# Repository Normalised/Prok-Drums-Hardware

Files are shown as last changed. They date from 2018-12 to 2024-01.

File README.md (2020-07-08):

# Prok-Drums-Hardware

Prok Drums are open hardware, they are a modified version of the Music Thing Modular Radio Music module by Tom Whitwell and have the Creative Commons license CC-BY-SA: Attribution / ShareAlike. 

If you use any work from this hardware, you should credit Tom Whitwell, and you must republish any changes you make under the same license. 

Please remove all references to Prok and Thonk from the PCB silkscreen and project name before republishing.

The names Prok and Thonk, their associated logos and module names are not open source and should not be used in any derivative works.

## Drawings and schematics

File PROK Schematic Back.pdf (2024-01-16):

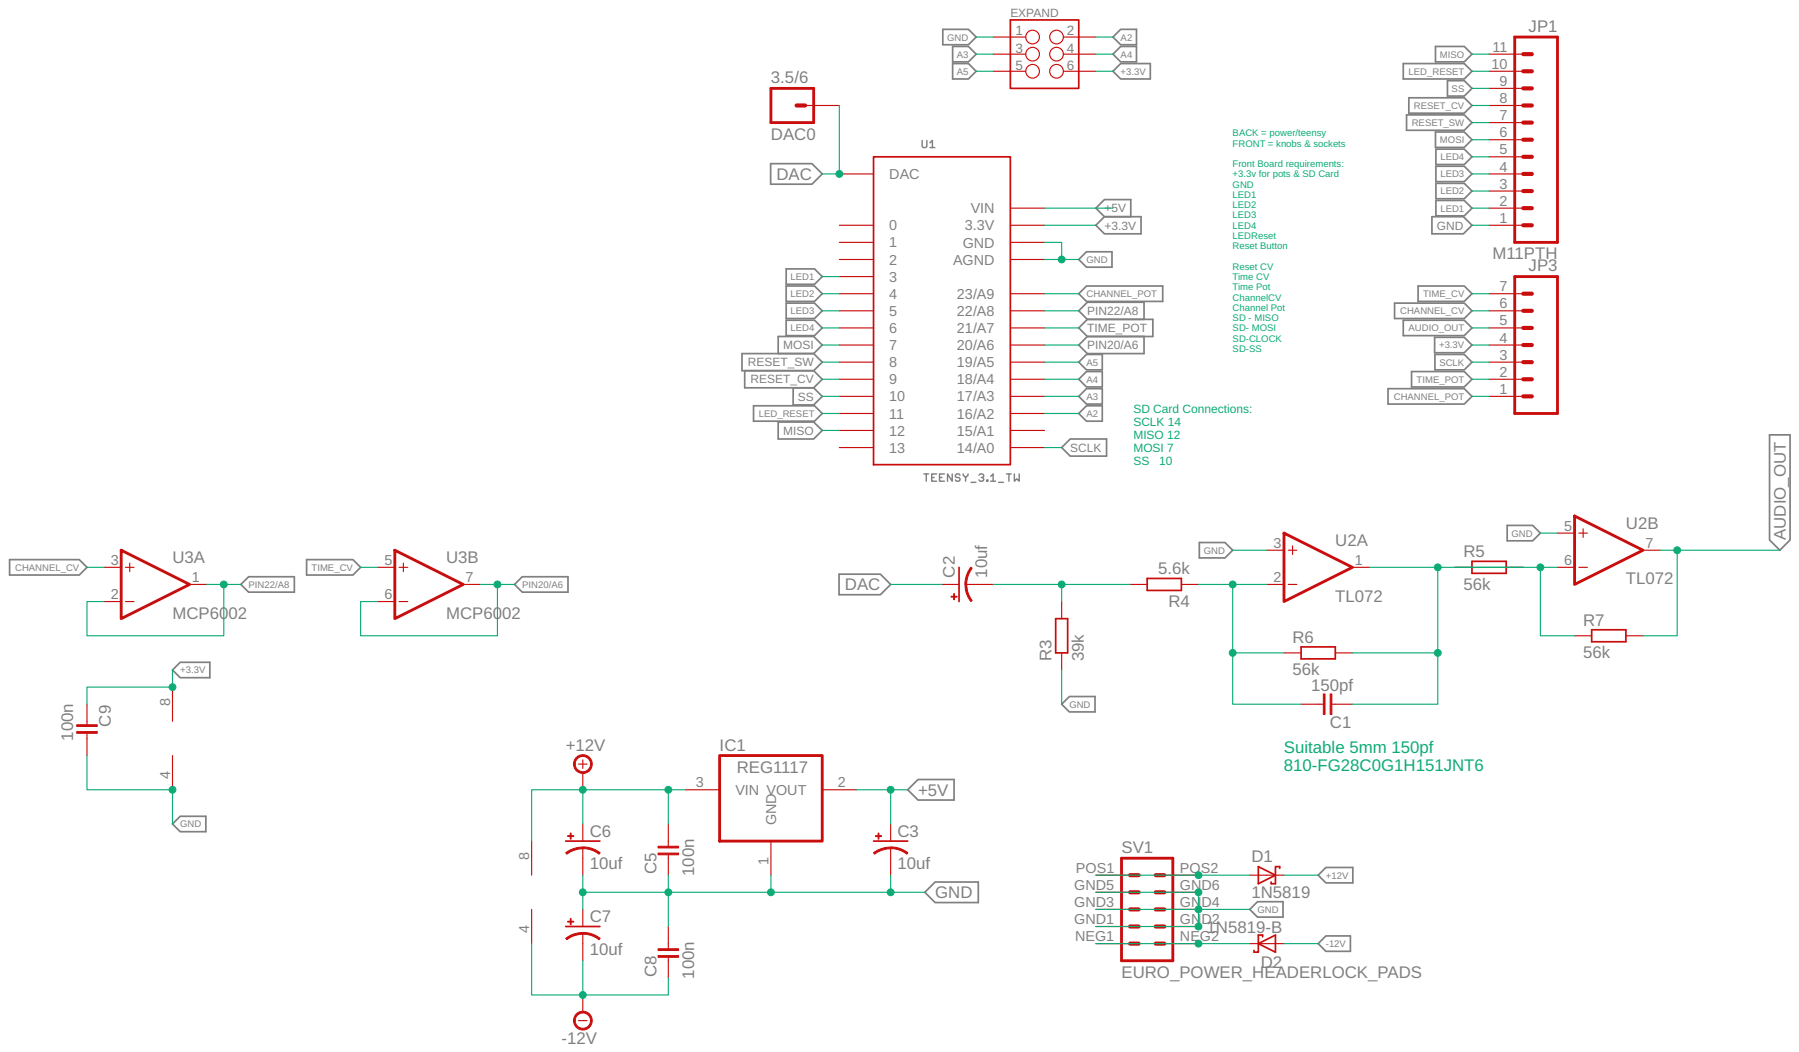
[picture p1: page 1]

BACK = power/teensy FRONT = knobs & sockets Front Board requirements: +3.3v for pots & SD Card GND

Time Pot ChannelCV Channel Pot SD - MISO

SD- MOSI SD-CLOCK

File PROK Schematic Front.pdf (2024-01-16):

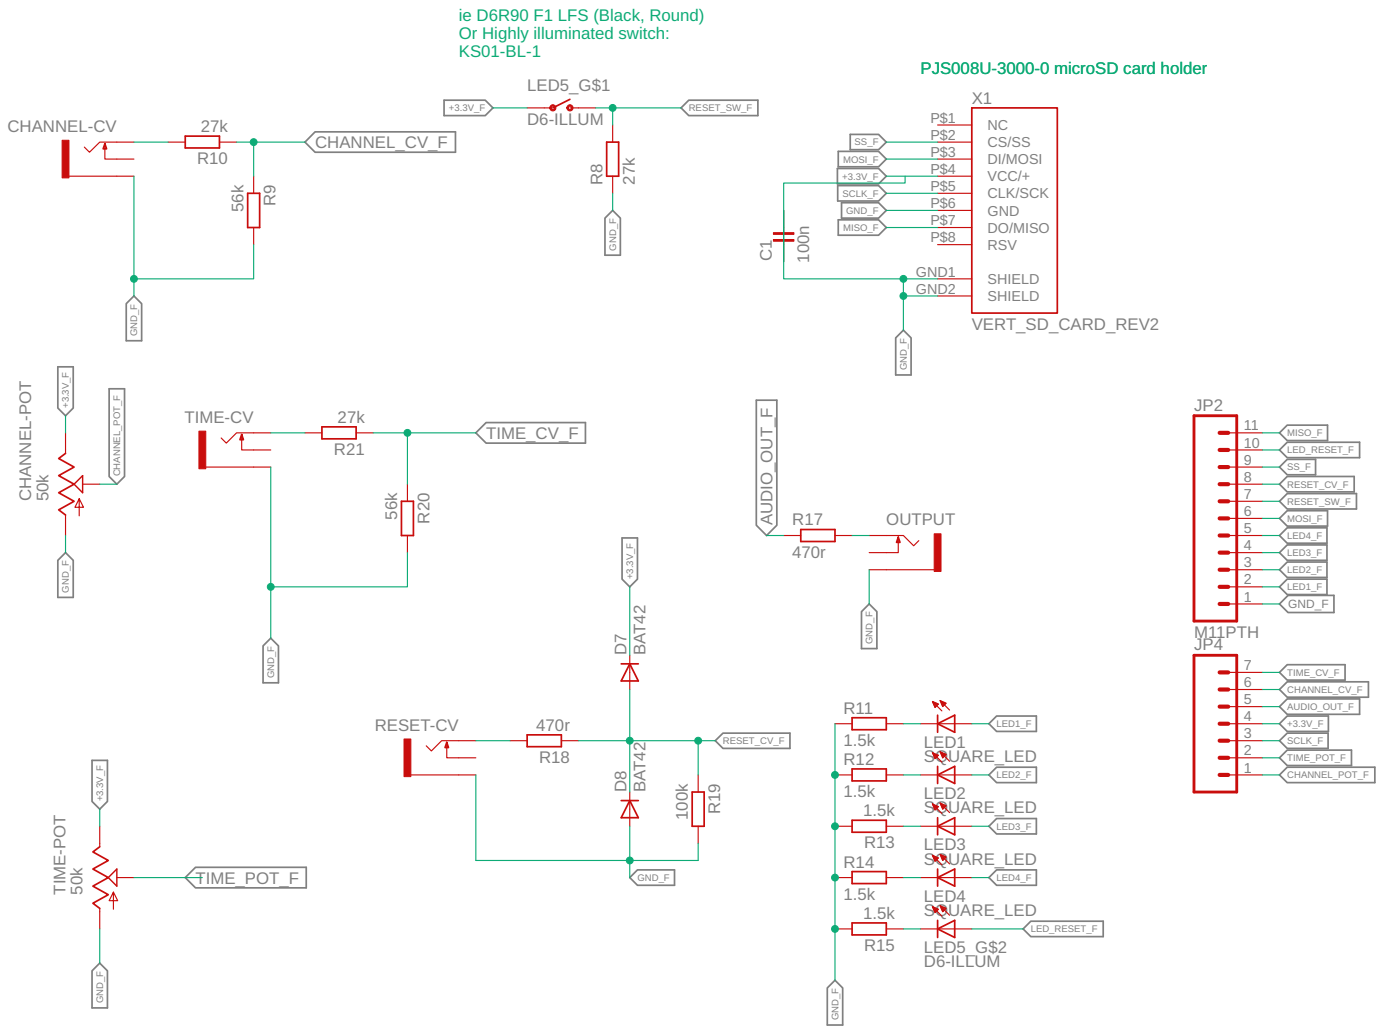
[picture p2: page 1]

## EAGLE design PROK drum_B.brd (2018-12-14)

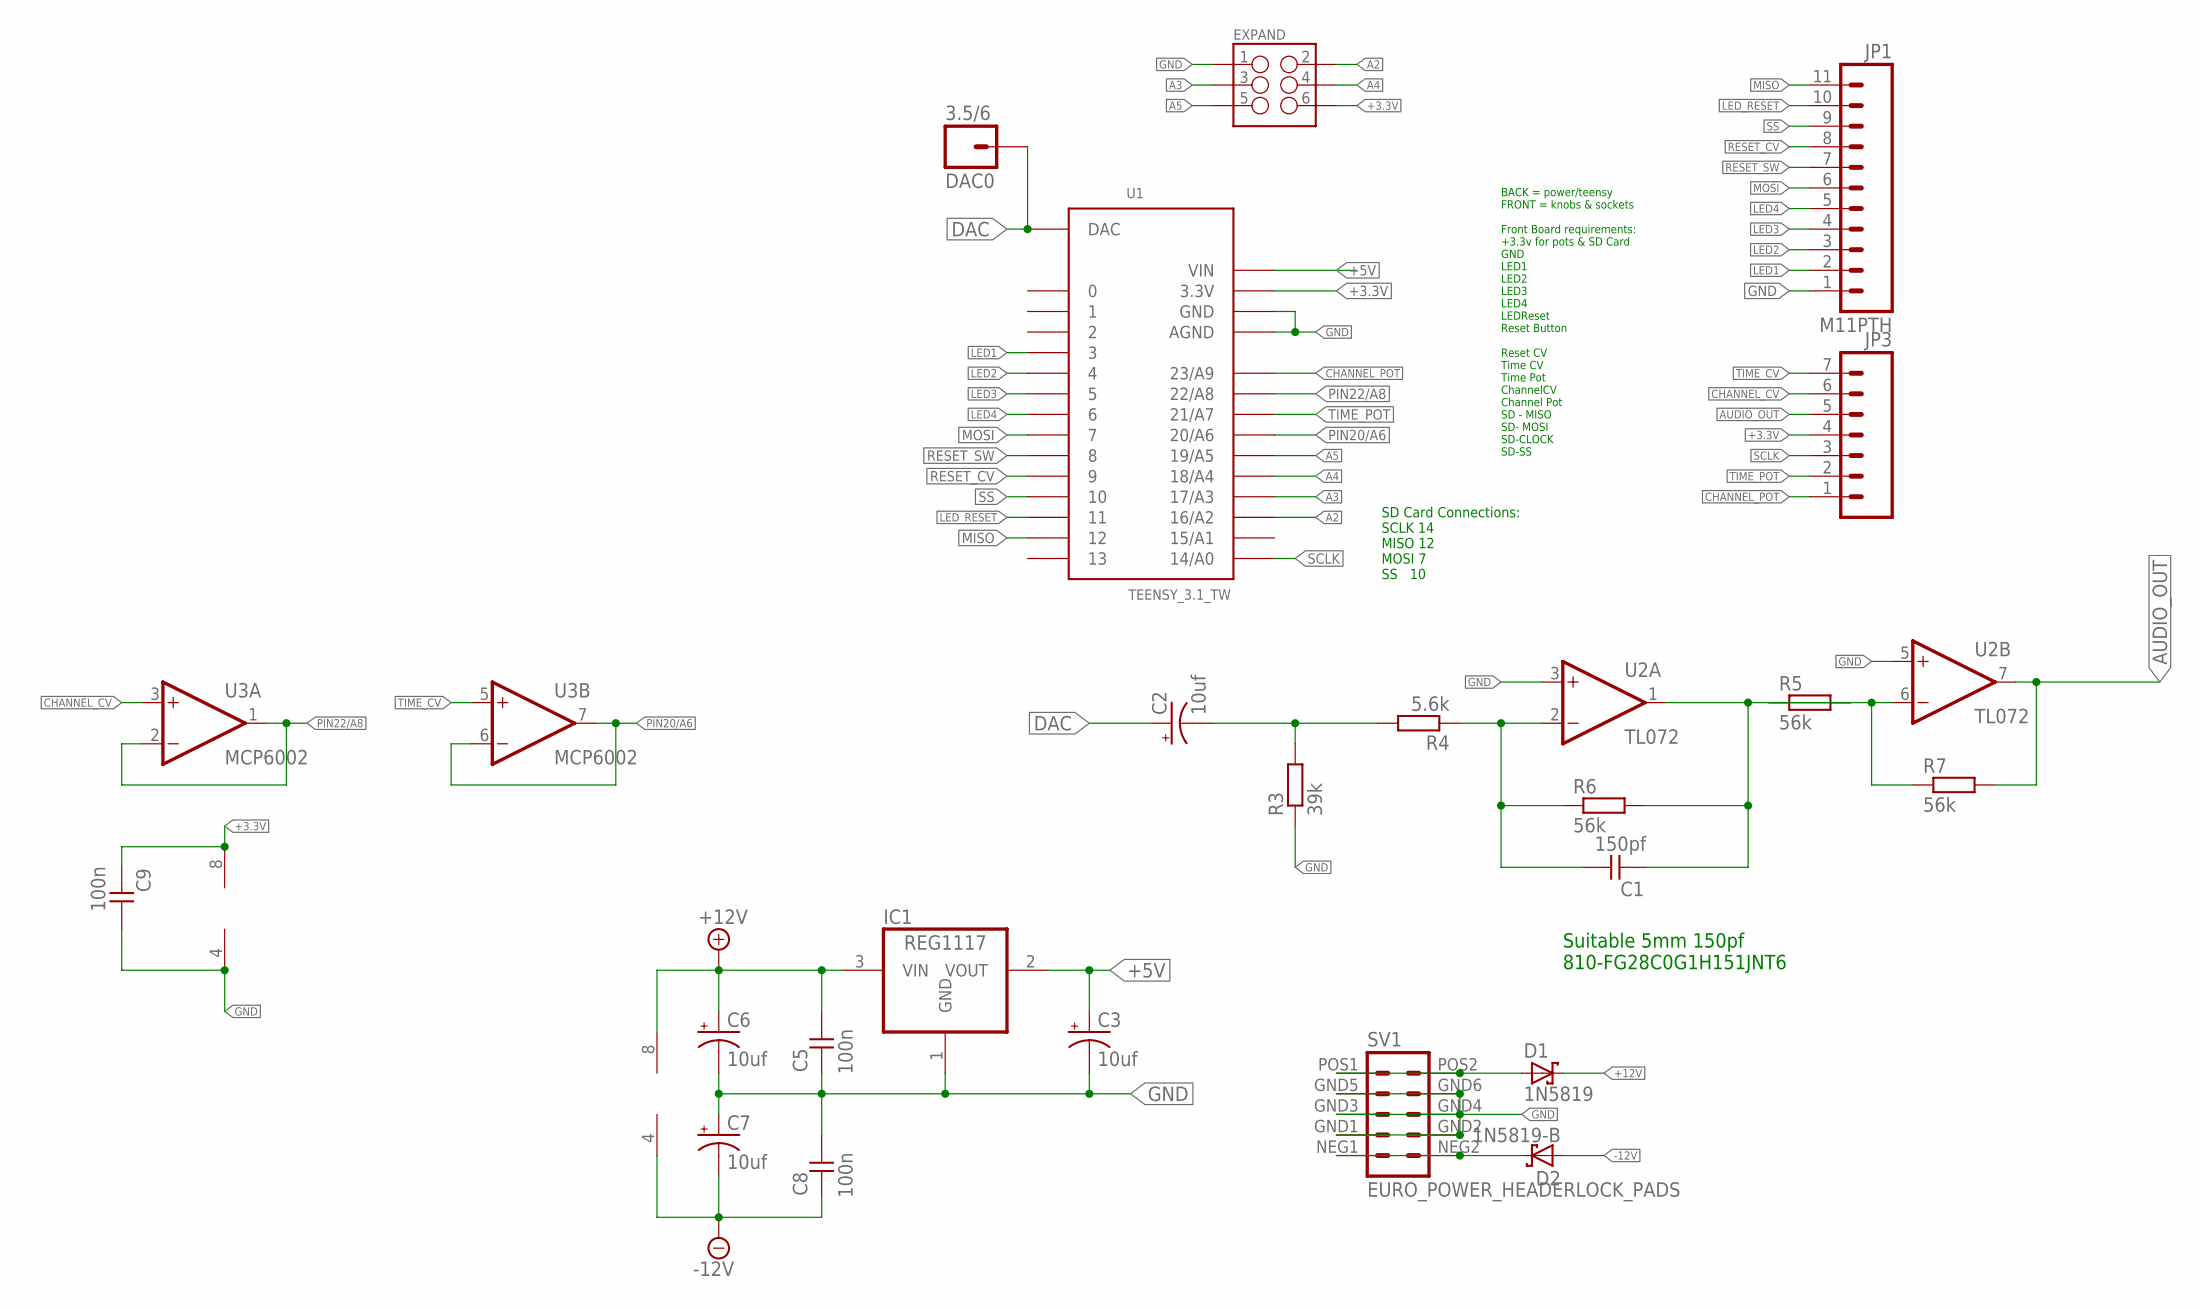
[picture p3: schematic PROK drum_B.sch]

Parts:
3.5/6: DAC0; 1X01
C1: 150pf; C050-024X044
C2, C3, C6, C7: 10uf; CPOL-RADIAL-10UF-25V
C5, C8, C9: 100n; C050-024X044
D1: 1N5819; DO41-7.6
D2: 1N5819-B; DO41-7.6
EXPAND: M03X22X3_SILK_SM; 2X3
IC1: REG1117; SOT223
JP1: M11PTH; 1X11
JP3: M07; 1X07
R3: 39k; 7MM_RESISTOR
R4: 5.6k; 7MM_RESISTOR
R5, R6, R7: 56k; 7MM_RESISTOR
SV1: EURO_POWER_HEADERLOCK_PADS; EURO_PWR_HEADER_LOCK
U1: TEENSY_3.1_TW
U2: TL072; DIL08-SML
U3: MCP6002; DIL08-SML

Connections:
+3.3V: C9.2, EXPAND.6, JP3.4, U1.3.3V, U3.8 (V+)
+5V: C3.1 (+), IC1.2 (VOUT), U1.VIN
+12V: C5.1, C6.1 (+), D1.C, IC1.3 (VIN), U2.8 (V+)
-12V: C7.2 (-), C8.2, D2.A, U2.4 (V-)
A2: EXPAND.2, U1.16/A2
A3: EXPAND.3, U1.17/A3
A4: EXPAND.4, U1.18/A4
A5: EXPAND.5, U1.19/A5
AUDIO_OUT: JP3.5, R7.2, U2.7 (OUT)
CHANNEL_CV: JP3.6, U3.3 (+IN)
CHANNEL_POT: JP3.1, U1.23/A9
DAC: 3.5/6.1, C2.1 (+), U1.DAC
GND: C3.2 (-), C5.2, C6.2 (-), C7.1 (+), C8.1, C9.1, EXPAND.1, IC1.1 (GND), JP1.1, R3.1, SV1.GND1 (4), SV1.GND2 (3), SV1.GND3 (6), SV1.GND4 (5), SV1.GND5 (8), SV1.GND6 (7), U1.AGND, U1.GND, U2.3 (+IN), U2.5 (+IN), U3.4 (V-)
LED1: JP1.2, U1.3
LED2: JP1.3, U1.4
LED3: JP1.4, U1.5
LED4: JP1.5, U1.6
LED_RESET: JP1.10, U1.11
MISO: JP1.11, U1.12
MOSI: JP1.6, U1.7
unnamed: C2.2 (-), R3.2, R4.2
unnamed: C1.1, R4.1, R6.1, U2.2 (-IN)
unnamed: R5.1, R7.1, U2.6 (-IN)
unnamed: C1.2, R5.2, R6.2, U2.1 (OUT)
unnamed: D1.A, SV1.POS1 (10), SV1.POS2 (9)
unnamed: D2.C, SV1.NEG1 (2), SV1.NEG2 (1)
PIN20/A6: U1.20/A6, U3.6 (-IN), U3.7 (OUT)
PIN22/A8: U1.22/A8, U3.1 (OUT), U3.2 (-IN)
RESET_CV: JP1.8, U1.9
RESET_SW: JP1.7, U1.8
SCLK: JP3.3, U1.14/A0
SS: JP1.9, U1.10
TIME_CV: JP3.7, U3.5 (+IN)
TIME_POT: JP3.2, U1.21/A7

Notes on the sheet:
SD Card Connections: SCLK 14 MISO 12 MOSI 7 SS 10
BACK = power/teensy FRONT = knobs & sockets Front Board requirements: +3.3v for pots & SD Card GND LED1 LED2 LED3 LED4 LEDReset Reset Button Reset CV Time CV Time Pot ChannelCV Channel Pot SD - MISO SD- MOSI SD-CLOCK SD-SS
Suitable 5mm 150pf 810-FG28C0G1H151JNT6

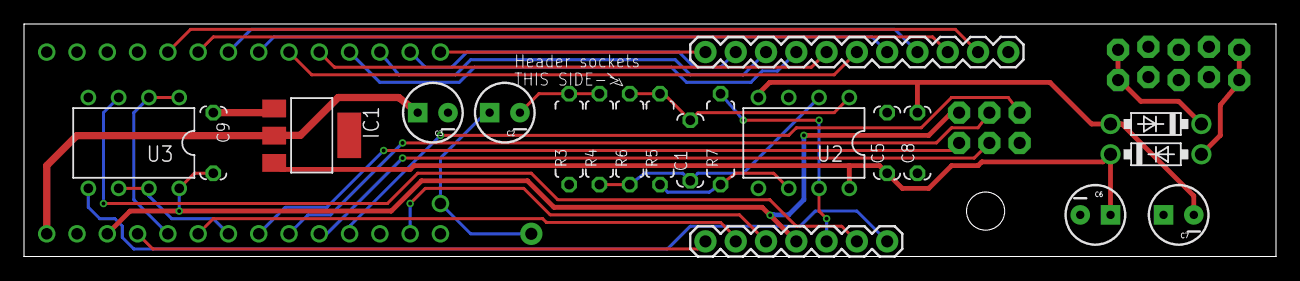
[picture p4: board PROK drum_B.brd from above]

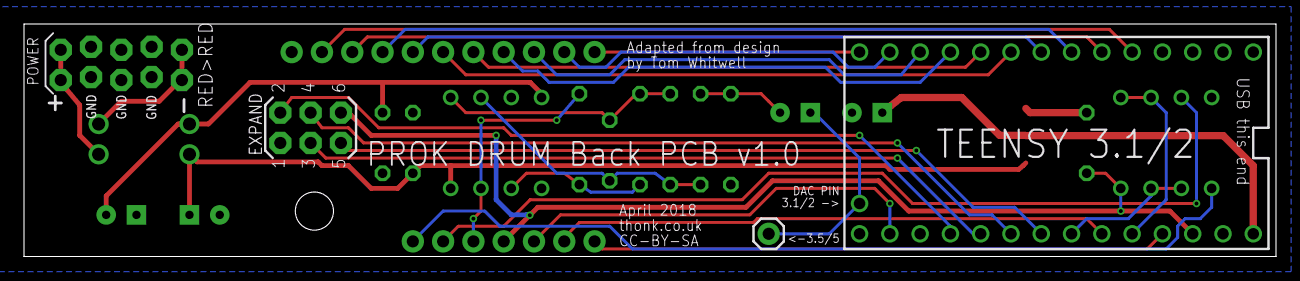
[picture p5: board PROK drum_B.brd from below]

Board: 4 copper layers, 105.0 x 19.5 mm, 25 parts (4 on the bottom side), 34 nets.

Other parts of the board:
U$1: MOUNTING_HOLE

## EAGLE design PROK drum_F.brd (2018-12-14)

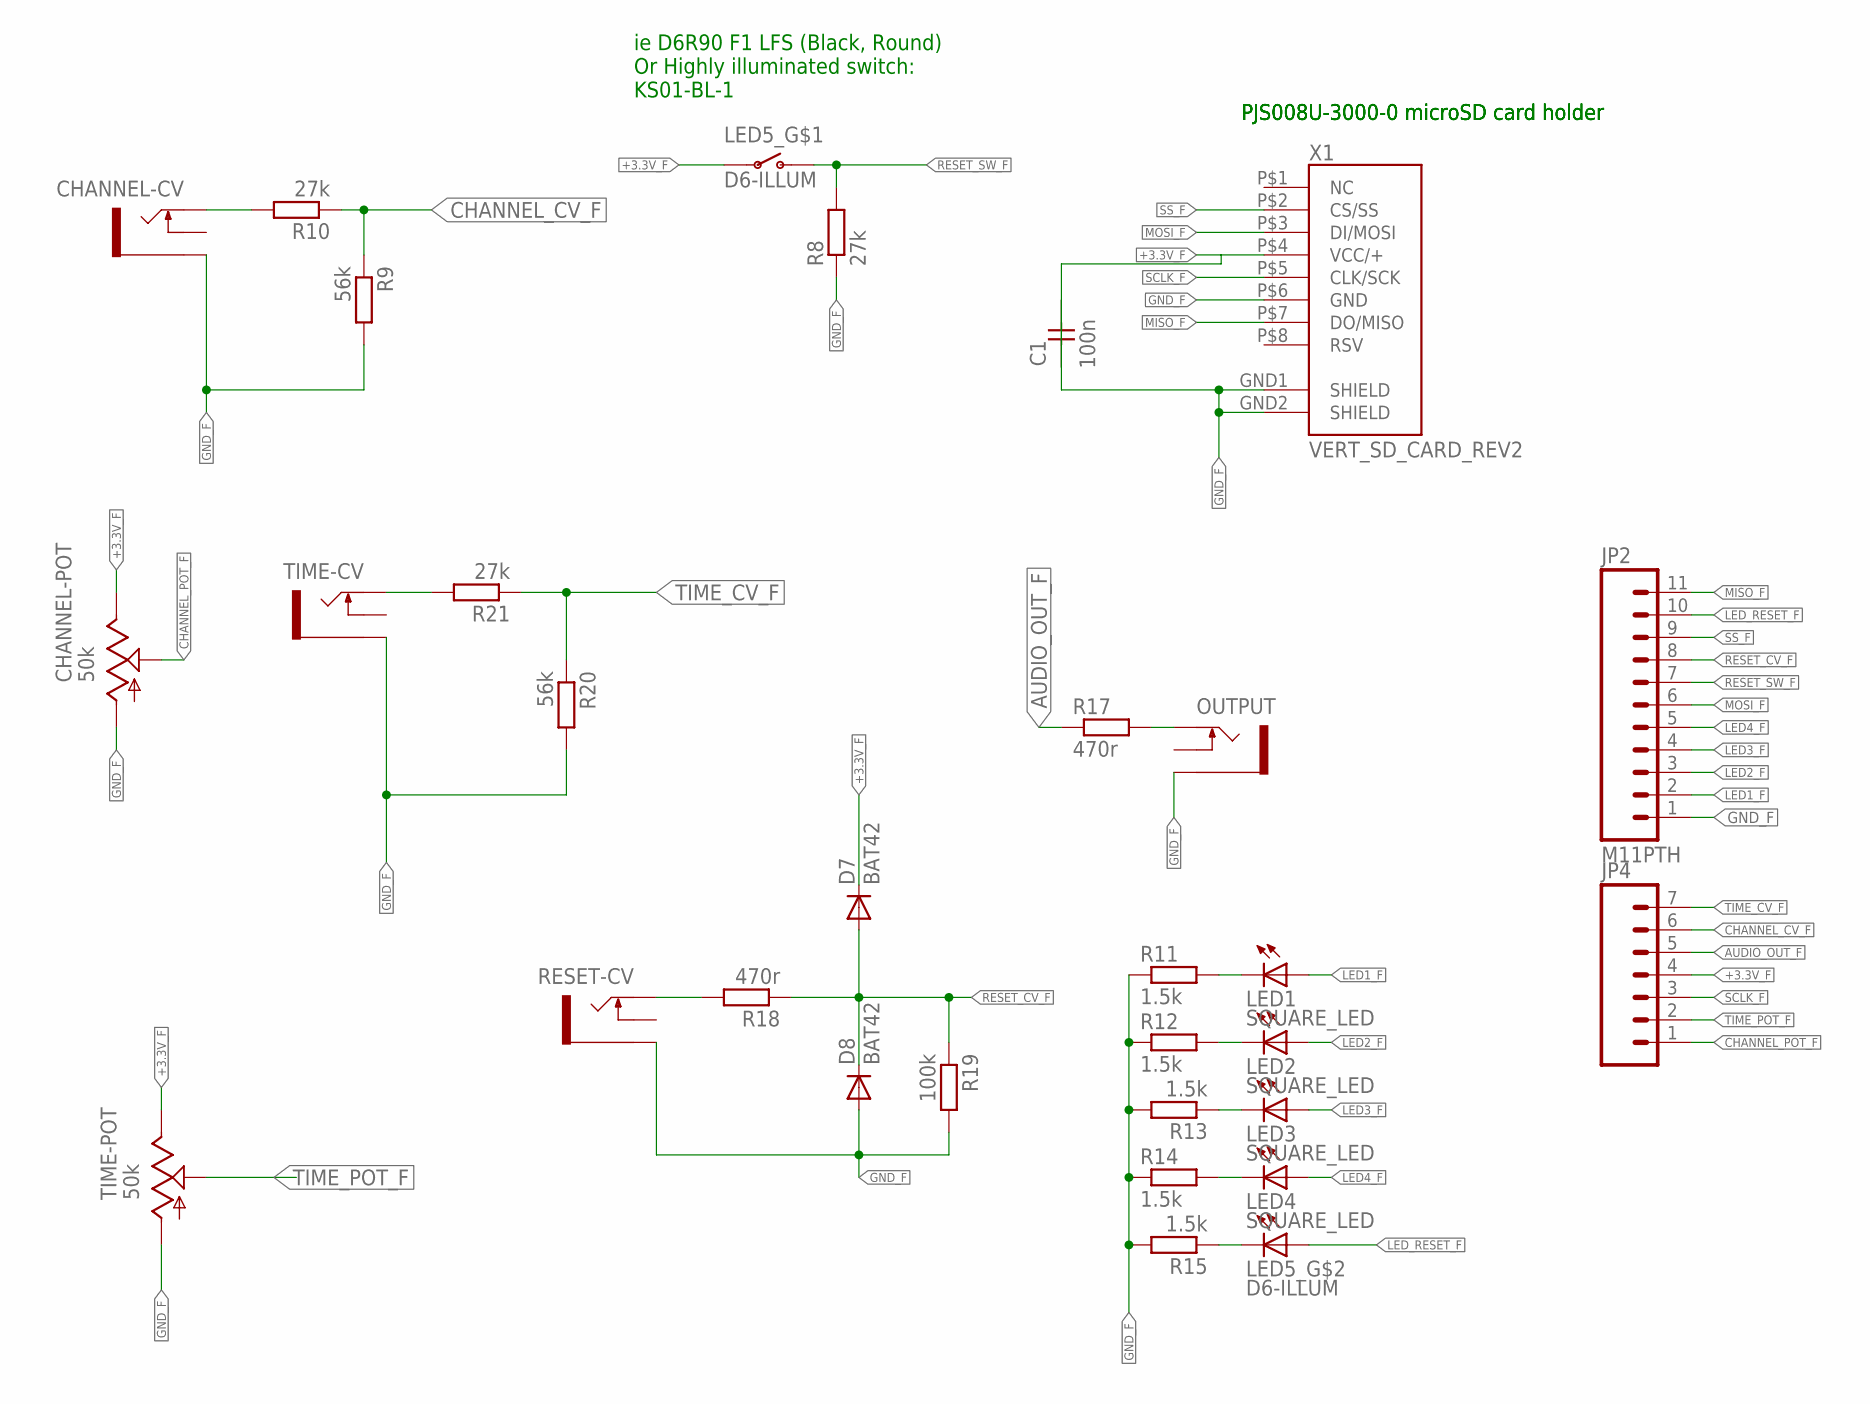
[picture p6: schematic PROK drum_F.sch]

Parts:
C1: 100n; C050-024X044
CHANNEL-CV: THONKICONNNEW; WQP-PJ301M-12_JACK
CHANNEL-POT: 50k; EVUF
D7, D8: BAT42; DO34-7
JP2: M11PTH; 1X11
JP4: M07; 1X07
LED1, LED2, LED3, LED4: SQUARE_LED
LED5_: D6-ILLUM; D6_PUSH_SWITCH_ILLUM
OUTPUT: THONKICONNNEW; WQP-PJ301M-12_JACK
R8: 27k; 7MM_RESISTOR
R9: 56k; 7MM_RESISTOR
R10, R21: 27k; VERTICAL_RESISTOR
R11, R12, R14, R15: 1.5k; 7MM_RESISTOR
R13: 1.5k; VERTICAL_RESISTOR
R17, R18: 470r; 7MM_RESISTOR
R19: 100k; 7MM_RESISTOR
R20: 56k; VERTICAL_RESISTOR
RESET-CV: THONKICONNNEW; WQP-PJ301M-12_JACK
TIME-CV: THONKICONNNEW; WQP-PJ301M-12_JACK
TIME-POT: 50k; EVUF
X1: VERT_SD_CARD_REV2; VERT_MICROSD_REV2

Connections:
+3.3V_F: C1.2, CHANNEL-POT.3 (E), D7.C, JP4.4, LED5_.P$3, LED5_.P$4, TIME-POT.3 (E), X1.P$4 (VCC/+)
AUDIO_OUT_F: JP4.5, R17.1
CHANNEL_CV_F: JP4.6, R9.1, R10.1
CHANNEL_POT_F: CHANNEL-POT.2 (S), JP4.1
GND_F: C1.1, CHANNEL-CV.P$3_SLEEVE (SLEEVE), CHANNEL-POT.1 (A), D8.A, JP2.1, OUTPUT.P$3_SLEEVE (SLEEVE), R8.1, R9.2, R11.1, R12.1, R13.2, R14.1, R15.2, R19.2, R20.2, RESET-CV.P$3_SLEEVE (SLEEVE), TIME-CV.P$3_SLEEVE (SLEEVE), TIME-POT.1 (A), X1.GND1 (SHIELD), X1.GND2 (SHIELD), X1.P$6 (GND)
LED1_F: JP2.2, LED1.ANODE (A)
LED2_F: JP2.3, LED2.ANODE (A)
LED3_F: JP2.4, LED3.ANODE (A)
LED4_F: JP2.5, LED4.ANODE (A)
LED_RESET_F: JP2.10, LED5_.LED+ (A)
MISO_F: JP2.11, X1.P$7 (DO/MISO)
MOSI_F: JP2.6, X1.P$3 (DI/MOSI)
unnamed: CHANNEL-CV.P$1_TIP (TIP), R10.2
unnamed: R21.2, TIME-CV.P$1_TIP (TIP)
unnamed: OUTPUT.P$1_TIP (TIP), R17.2
unnamed: R18.2, RESET-CV.P$1_TIP (TIP)
unnamed: LED1.CATHODE (C), R11.2
unnamed: LED2.CATHODE (C), R12.2
unnamed: LED3.CATHODE (C), R13.1
unnamed: LED4.CATHODE (C), R14.2
unnamed: LED5_.LED- (C), R15.1
RESET_CV_F: D7.A, D8.C, JP2.8, R18.1, R19.1
RESET_SW_F: JP2.7, LED5_.P$1 (O), LED5_.P$2 (O), R8.2
SCLK_F: JP4.3, X1.P$5 (CLK/SCK)
SS_F: JP2.9, X1.P$2 (CS/SS)
TIME_CV_F: JP4.7, R20.1, R21.1
TIME_POT_F: JP4.2, TIME-POT.2 (S)

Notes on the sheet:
ie D6R90 F1 LFS (Black, Round) Or Highly illuminated switch: KS01-BL-1
PJS008U-3000-0 microSD card holder

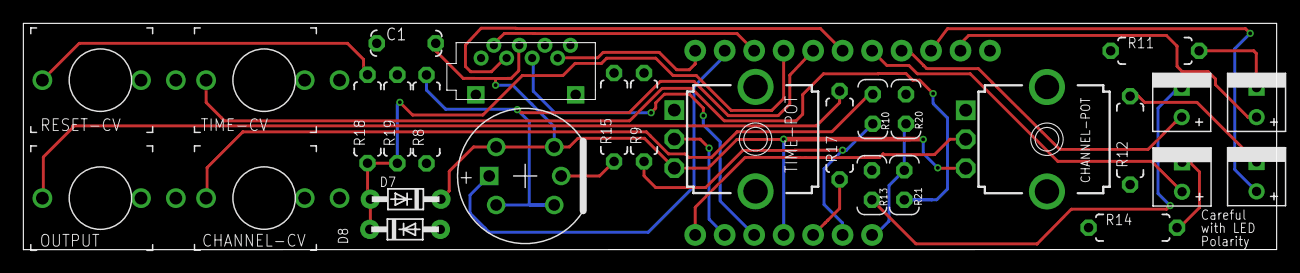
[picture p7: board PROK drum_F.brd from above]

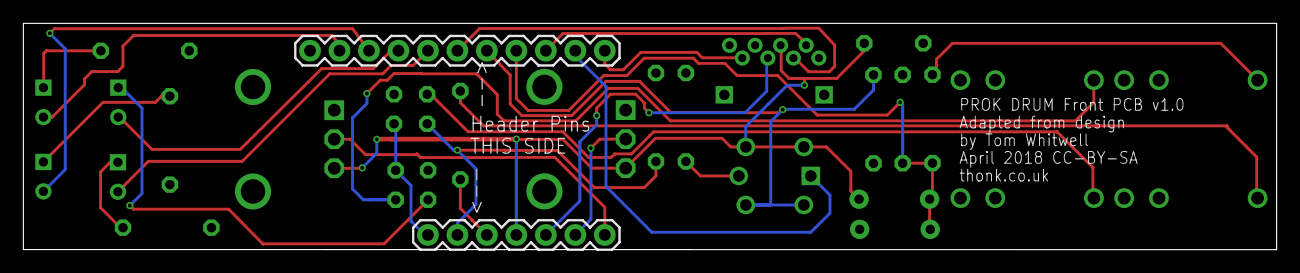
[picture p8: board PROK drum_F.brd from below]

Board: 4 copper layers, 108.0 x 19.5 mm, 30 parts (2 on the bottom side), 27 nets.

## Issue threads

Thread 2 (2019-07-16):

Trigger issues?

pirwin2, 2019-07-16:
Hi - I have built 4 of these modules and have noticed that none of them will trigger from some sources, for example my TipTop Audio Trigger Riot. X & Y CVs respond to it, but not the trigger.
If I route the same signal via a clock divider it will trigger, so is there a higher voltage threshold on the trigger or some reason why it won't respond under normal circumstances?
Thanks!

Closed 2019-07-17.

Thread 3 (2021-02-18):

Significant background hum

sawtoothwave, 2021-02-18:
Loving the sound of the Prok modules so far (built all 4 of them, and then converted the clap to a Klonk), but there's much more background hum/noise than I had expected. I don't mean the low-fi crunch of the 12 bit audio, I mean more like, 60-cycle hum, etc.

I don't think it's from my build since the modules are working perfectly otherwise. It's a little worse in the Snare and Hihat modules, I think, than in the BD and Klonk. It's possible my power supply (Doepfer A-100 DIY kit, so not super high end) isn't helping. Just thought I'd mention to see if it's a known issue, and if there's a chance it's software and could be fixed in a future firmware upgrade.

Thanks!

sawtoothwave, 2021-02-18:
Just to add a little more context - it's not just hissy noise, which I think I'd be more ok with, it's a very obvious pitched tone. I recorded the background noise from my system and then moved the faders up on the VCA carrying each of the Prok drums one at a time - BD, SD, HH, Klonk (running on a Clap module) as a reference. It starts with 5 seconds of background noise and then moves on to the above in sequence. Thanks!

[Prok noise BD SD HH KL.mp3.zip](https://github.com/Normalised/Prok-Drums-Hardware/files/6006447/Prok.noise.BD.SD.HH.KL.mp3.zip)

nebularnoise, 2021-02-20:
Yeah, I've opened a ticket myself. I'm fairly certain this has to do with the LEDs

sawtoothwave, 2021-02-22:
Are you hearing the same pitched whine that I am, differing from module to module depending on the firmware? I've been concerned that maybe I just messed up the build, but it doesn't seem like that.

nebularnoise, 2021-02-26:
yep. I've built 5 proks. They consistently do this, and indeed, the pitch changes with the firmware.

sawtoothwave, 2021-03-21:
Any thoughts from the Prok team on whether this is something that could/might/will be improved in a future firmware? I really love the sound, usability, and flexibility of these modules—pretty much the only thing I could think of to improve would be velocity sensitivity—but the pitched background hum is suuuuuper audible (especially if you compress the drums) in anything but the very busiest mixes.

I'd be very encouraged to hear that this is something that could be addressed in a future firmware, however long it may take for that to happen.

milesjohnson777, 2021-07-16:
im also having this issue and it even happens when i move my SN out of my custom rig to my tiptop mantis case. i got my module as a diy build so i dont mind performing a hardware mod to fix this if it just needs a capacitor to filter it or something

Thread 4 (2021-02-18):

LED PWM in audible spectrum

nebularnoise, 2021-02-18:
Hi!
Could it be possible to raise the PWM frequency of the LEDs to be beyond 24kHz ?
Currently, it's well in the audible spectrum, and it's causing noise issues for a lot of people.

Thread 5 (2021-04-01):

Teensy for BD dead??

GrosBob, 2021-04-01:
Hi,

Sorry to post here, but I cannot figure out where was the bes place to do so.
I face serious a problem since yesterday with the BD module (I have all the four). It didn't fire up as usual.. No leds, nothing.
As I own the 3 other module I swapped the supposed faulty teensy board with all the three others and they work perfectly. The reverse was also confirmed. So all my 4 modules are OK but I have the BD teensy not working any more. Its led (on the board) do not flashes on startup, the three others do. and obviously this board is not recognized by DrumCentral and DrumEditor.
I'm wondering what happens. And is there a way to try to correct this issue? FW problem? or a more serious HW failure?
Any ideas or suggestions to have it working back again?
Thanks in advance for your returns

Eric

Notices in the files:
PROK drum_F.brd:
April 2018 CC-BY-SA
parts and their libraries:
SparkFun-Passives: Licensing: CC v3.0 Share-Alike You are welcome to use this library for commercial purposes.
